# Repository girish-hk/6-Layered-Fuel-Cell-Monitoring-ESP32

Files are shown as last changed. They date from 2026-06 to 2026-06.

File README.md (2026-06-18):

# 6-Layered Fuel Cell Monitoring ESP32

A six-layer fuel cell monitoring PCB designed in KiCad for accurate voltage and current measurement. The system integrates analog signal conditioning, precision ADC interfaces, and an ESP32-S3 microcontroller for data acquisition and processing.

## Features

* 6-layer PCB design
* Fuel cell voltage monitoring
* Fuel cell current monitoring
* ESP32-S3 integration
* Custom KiCad symbols and footprints
* 3D PCB model

## Tools

* KiCad
* ESP32-S3
* Git & GitHub

## Preview

PCB Layout and 3D Render included in the repository.

## Author

Girish H K

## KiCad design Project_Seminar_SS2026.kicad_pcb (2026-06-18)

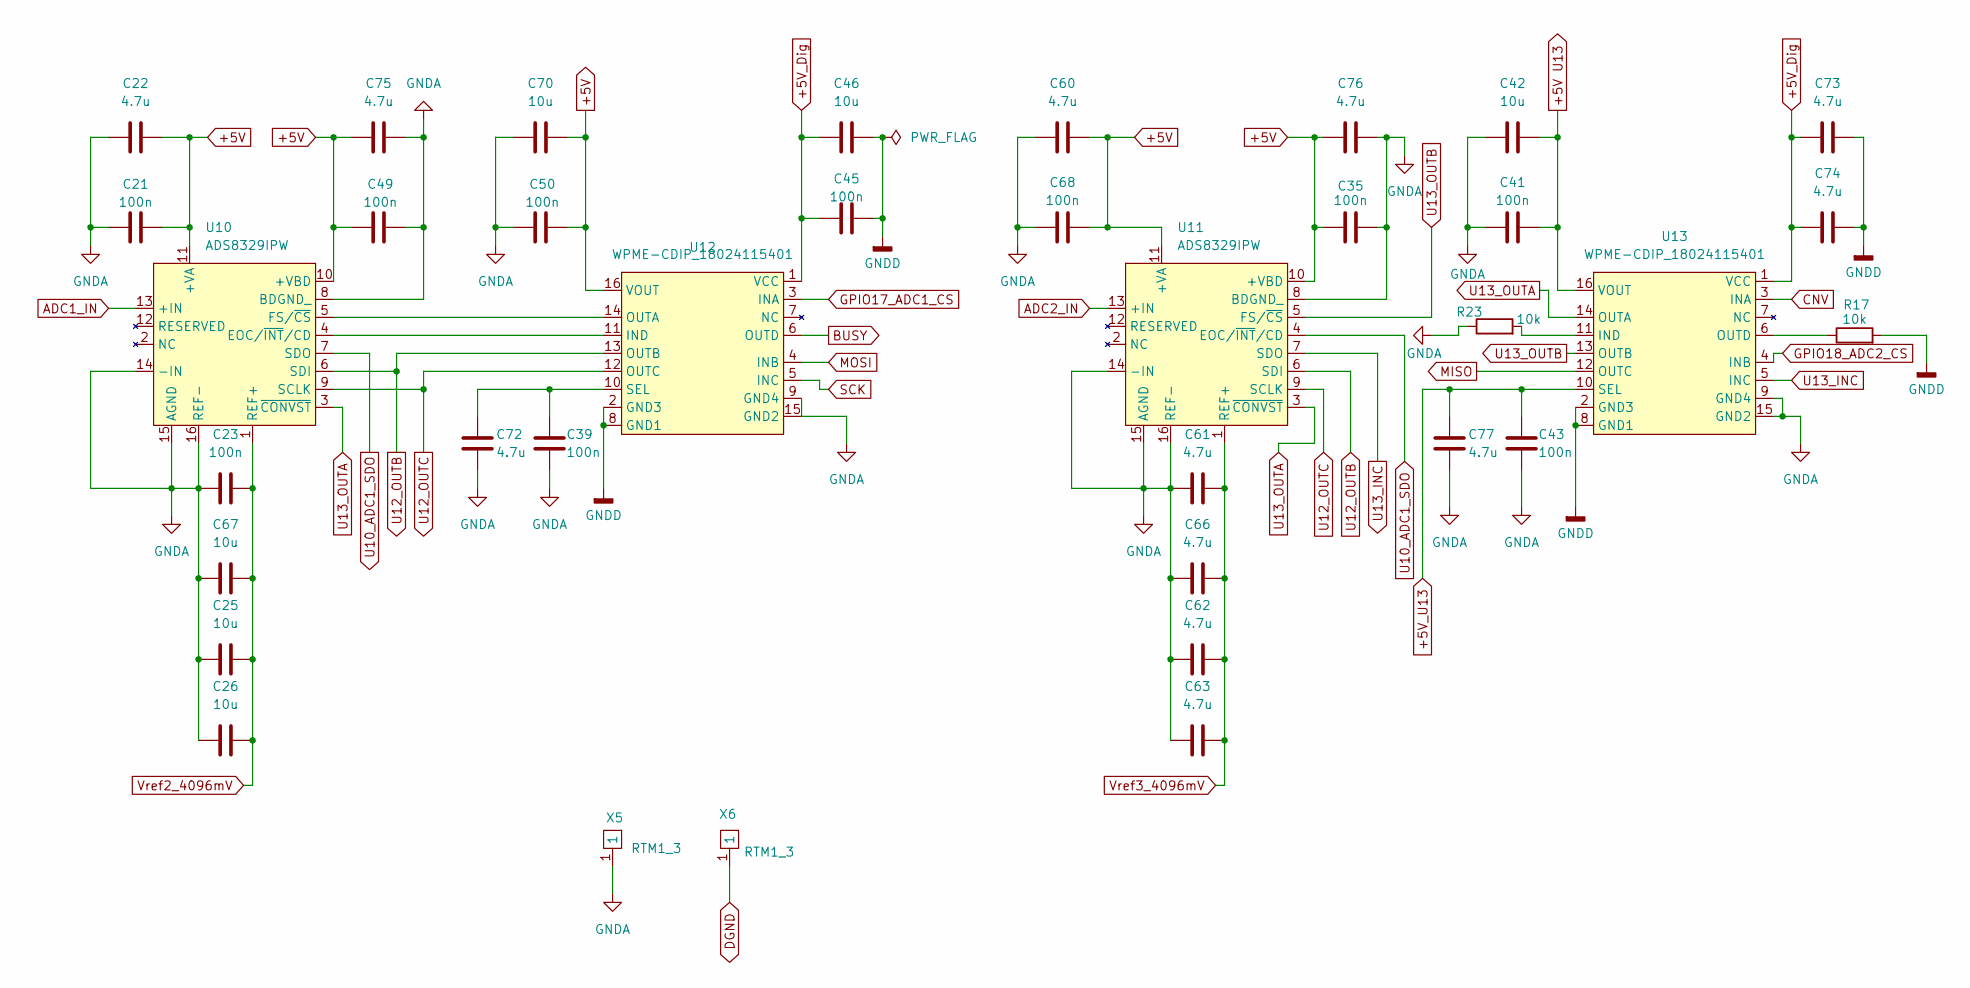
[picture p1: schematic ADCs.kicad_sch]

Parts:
C21, C23, C35, C39, C41, C43, C45, C49, C50, C68: 100n; C_0402_1005Metric
C22, C60, C61, C62, C63, C66, C72, C73, C74, C75, C76, C77: 4.7u; C_0402_1005Metric
C25, C26, C42, C46, C67, C70: 10u; C_0402_1005Metric
R17, R23: 10k; R_0402_1005Metric
U10, U11: ADS8329IPW; ADS8329
U12, U13: WPME-CDIP_18024115401
X5, X6: RTM1_3; rtm

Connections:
+5V: C21.2, C22.2, C35.1, C49.1, C50.2, C60.2, C68.2, C70.2, C75.1, C76.1, U10.10 (+VBD), U10.11 (+VA), U11.10 (+VBD), U11.11 (+VA), U12.16 (VOUT); also elsewhere on the board
+5V U13: C41.2, C42.2, U13.16 (VOUT)
+5V_Dig: C45.1, C46.1, C73.1, C74.1, U12.1 (VCC), U13.1 (VCC); also elsewhere on the board
+5V_U13: C43.2, C77.2, U13.10 (SEL)
ADC1_IN: U10.13 (+IN); also elsewhere on the board
ADC2_IN: U11.13 (+IN); also elsewhere on the board
BUSY: U12.6 (OUTD); also elsewhere on the board
CNV: U13.3 (INA); also elsewhere on the board
DGND: X6.1; also elsewhere on the board
GNDA: C21.1, C22.1, C23.1, C25.1, C26.1, C35.2, C39.1, C41.1, C42.1, C43.1, C49.2, C50.1, C60.1, C61.1, C62.1, C63.1, C66.1, C67.1, C68.1, C70.1, C72.1, C75.2, C76.2, C77.1, R23.1, U10.8 (BDGND_), U10.14 (-IN), U10.15 (AGND), U10.16 (REF−), U11.8 (BDGND_), U11.14 (-IN), U11.15 (AGND), U11.16 (REF−), U12.9 (GND4), U12.15 (GND2), U13.9 (GND4), U13.15 (GND2), X5.1; also elsewhere on the board
GNDD: C45.2, C46.2, C73.2, C74.2, R17.2, U12.2 (GND3), U12.8 (GND1), U13.2 (GND3), U13.8 (GND1)
GPIO17_ADC1_CS: U12.3 (INA); also elsewhere on the board
GPIO18_ADC2_CS: U13.4 (INB); also elsewhere on the board
MISO: U13.12 (OUTC); also elsewhere on the board
MOSI: U12.4 (INB); also elsewhere on the board
unnamed: U10.4 (EOC/~INT/CD), U12.11 (IND)
unnamed: U10.5 (FS/~CS), U12.14 (OUTA)
unnamed: C39.2, C72.2, U12.10 (SEL)
unnamed: R23.2, U13.11 (IND)
unnamed: R17.1, U13.6 (OUTD)
SCK: U12.5 (INC); also elsewhere on the board
U10_ADC1_SDO: U10.7 (SDO), U11.4 (EOC/~INT/CD)
U12_OUTB: U10.6 (SDI), U11.6 (SDI), U12.13 (OUTB)
U12_OUTC: U10.9 (SCLK), U11.9 (SCLK), U12.12 (OUTC)
U13_INC: U11.7 (SDO), U13.5 (INC)
U13_OUTA: U10.3 (~CONVST), U11.3 (~CONVST), U13.14 (OUTA)
U13_OUTB: U11.5 (FS/~CS), U13.13 (OUTB)
Vref2_4096mV: C23.2, C25.2, C26.2, C67.2, U10.1 (REF+); also elsewhere on the board
Vref3_4096mV: C61.2, C62.2, C63.2, C66.2, U11.1 (REF+)

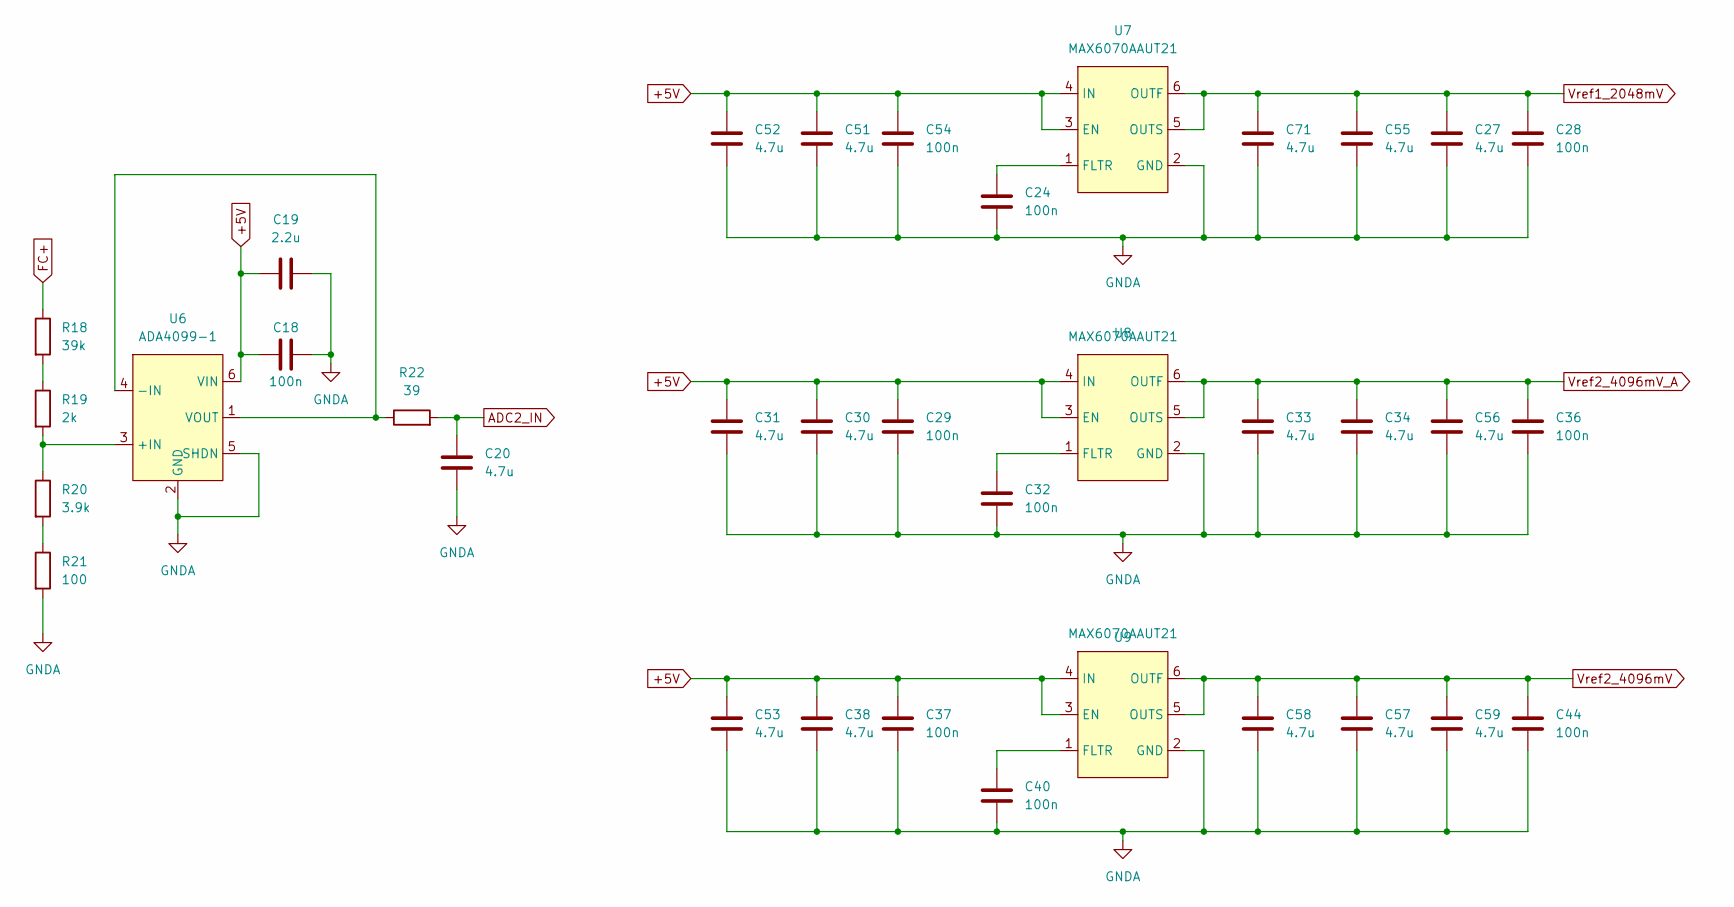
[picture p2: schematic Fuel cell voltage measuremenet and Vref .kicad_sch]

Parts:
C18, C24, C28, C29, C32, C36, C37, C40, C44, C54: 100n; C_0402_1005Metric
C19: 2.2u; C_0402_1005Metric
C20, C27, C30, C31, C33, C34, C38, C51, C52, C53, C55, C56, C57, C58, C59, C71: 4.7u; C_0402_1005Metric
R18: 39k; R_0603_1608Metric
R19: 2k; R_0603_1608Metric
R20: 3.9k; R_0603_1608Metric
R21: 100; R_0603_1608Metric
R22: 39; R_0402_1005Metric
U6: ADA4099-1; ADA4099
U7, U8, U9: MAX6070AAUT21; MAX6070

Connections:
+5V: C18.1, C19.1, C29.1, C30.1, C31.1, C37.1, C38.1, C51.1, C52.1, C53.1, C54.1, U6.6 (VIN), U7.3 (EN), U7.4 (IN), U8.3 (EN), U8.4 (IN), U9.3 (EN), U9.4 (IN); also elsewhere on the board
ADC2_IN: C20.1, R22.2; also elsewhere on the board
FC+: R18.1; also elsewhere on the board
GNDA: C18.2, C19.2, C20.2, C24.2, C27.2, C28.2, C29.2, C30.2, C31.2, C32.2, C33.2, C34.2, C36.2, C37.2, C38.2, C40.2, C44.2, C51.2, C52.2, C53.2, C54.2, C55.2, C56.2, C57.2, C58.2, C59.2, C71.2, R21.2, U6.2 (GND), U6.5 (SHDN), U7.2 (GND), U8.2 (GND), U9.2 (GND); also elsewhere on the board
unnamed: R18.2, R19.1
unnamed: R20.2, R21.1
unnamed: R19.2, R20.1, U6.3 (+IN)
unnamed: R22.1, U6.1 (VOUT), U6.4 (-IN)
unnamed: C24.1, U7.1 (FLTR)
unnamed: C32.1, U8.1 (FLTR)
unnamed: C40.1, U9.1 (FLTR)
Vref1_2048mV: C27.1, C28.1, C55.1, C71.1, U7.5 (OUTS), U7.6 (OUTF); also elsewhere on the board
Vref2_4096mV: C44.1, C57.1, C58.1, C59.1, U9.5 (OUTS), U9.6 (OUTF); also elsewhere on the board
Vref2_4096mV_A: C33.1, C34.1, C36.1, C56.1, U8.5 (OUTS), U8.6 (OUTF)

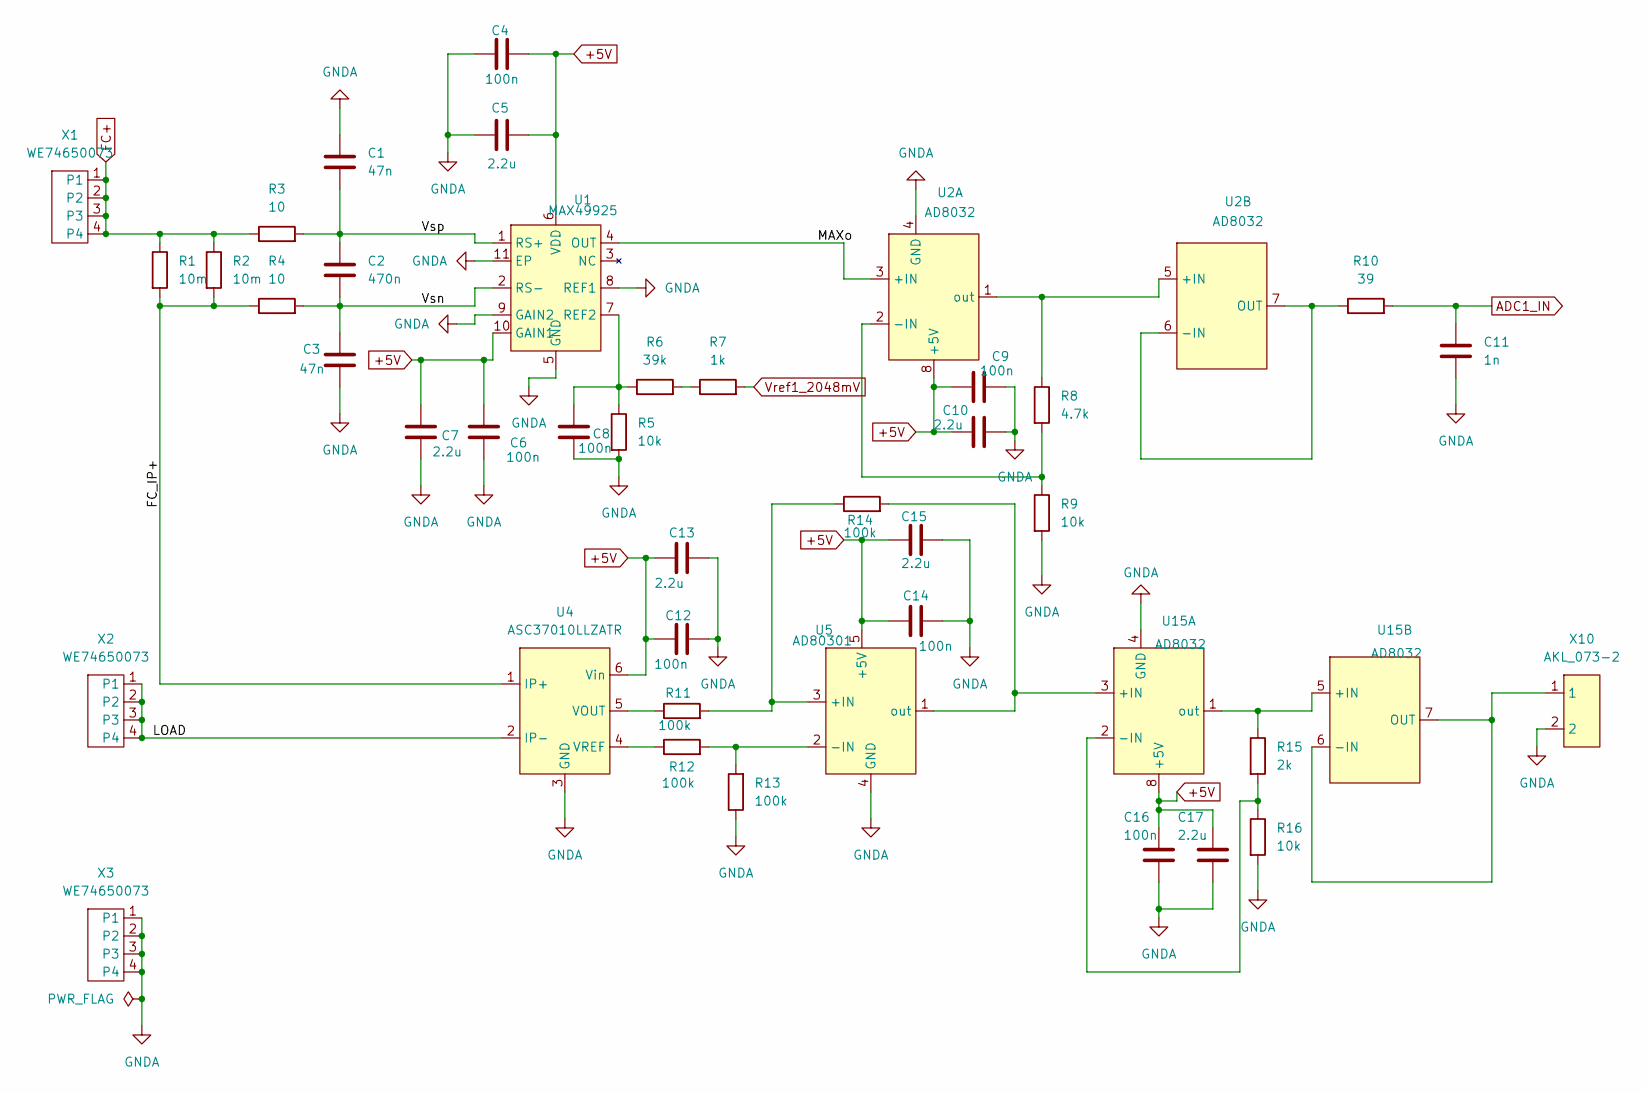
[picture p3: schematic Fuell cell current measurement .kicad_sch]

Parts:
C1, C3: 47n; C_0603_1608Metric
C2: 470n; C_0603_1608Metric
C4, C6, C8, C9, C12, C14, C16: 100n; C_0402_1005Metric
C5, C7, C10, C13, C15, C17: 2.2u; C_0402_1005Metric
C11: 1n; C_0402_1005Metric
R1, R2: 10m; R_2512_6332Metric
R3, R4: 10; R_0603_1608Metric
R5, R9, R16: 10k; R_0402_1005Metric
R6: 39k; R_0402_1005Metric
R7: 1k; R_0402_1005Metric
R8: 4.7k; R_0402_1005Metric
R10: 39; R_0402_1005Metric
R11, R12, R13, R14: 100k; R_0402_1005Metric
R15: 2k; R_0402_1005Metric
U1: MAX49925; MAX49925_TDFN10_3x3_EP
U2, U15: AD8032
U4: ASC37010LLZATR; ACS37010LLZATR-030U5
U5: AD80301; AD8031
X1, X2, X3: WE74650073; WP-THRBU REDCUBE 74650073
X10: AKL_073-2; AKLO73-2

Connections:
+5V: C4.2, C5.2, C6.1, C7.1, C9.1, C10.1, C12.1, C13.1, C14.1, C15.1, C16.2, C17.1, U1.6 (VDD), U1.10 (GAIN1), U2.8 (+5V), U4.6 (Vin), U5.5 (+5V), U15.8 (+5V); also elsewhere on the board
/Fuel cell current measurement (page 2)/FC_IP+: R1.2, R2.2, R4.1, U4.1 (IP+)
/Fuel cell current measurement (page 2)/LOAD: U4.2 (IP-), X2.1, X2.2, X2.3, X2.4
/Fuel cell current measurement (page 2)/MAXo: U1.4 (OUT), U2.3 (+IN)
/Fuel cell current measurement (page 2)/Vsn: C2.2, C3.1, R4.2, U1.2 (RS-)
/Fuel cell current measurement (page 2)/Vsp: C1.2, C2.1, R3.2, U1.1 (RS+)
ADC1_IN: C11.1, R10.2; also elsewhere on the board
FC+: R1.1, R2.1, R3.1, X1.1, X1.2, X1.3, X1.4; also elsewhere on the board
GNDA: C1.1, C3.2, C4.1, C5.1, C6.2, C7.2, C8.2, C9.2, C10.2, C11.2, C12.2, C13.2, C14.2, C15.2, C16.1, C17.2, R5.2, R9.2, R13.1, R16.2, U1.5 (GND), U1.8 (REF1), U1.9 (GAIN2), U1.11 (EP), U2.4 (GND), U4.3 (GND), U5.4 (GND), U15.4 (GND), X3.1, X3.2, X3.3, X3.4, X10.2; also elsewhere on the board
unnamed: R6.2, R7.1
unnamed: C8.1, R5.1, R6.1, U1.7 (REF2)
unnamed: R8.2, R9.1, U2.2 (-IN)
unnamed: R8.1, U2.1 (out), U2.5 (+IN)
unnamed: R10.1, U2.6 (-IN), U2.7 (OUT)
unnamed: R11.1, U4.5 (VOUT)
unnamed: R12.1, U4.4 (VREF)
unnamed: R11.2, R14.1, U5.3 (+IN)
unnamed: R12.2, R13.2, U5.2 (-IN)
unnamed: R14.2, U5.1 (out), U15.3 (+IN)
unnamed: R15.2, R16.1, U15.2 (-IN)
unnamed: R15.1, U15.1 (out), U15.5 (+IN)
unnamed: U15.6 (-IN), U15.7 (OUT), X10.1
Vref1_2048mV: R7.2; also elsewhere on the board

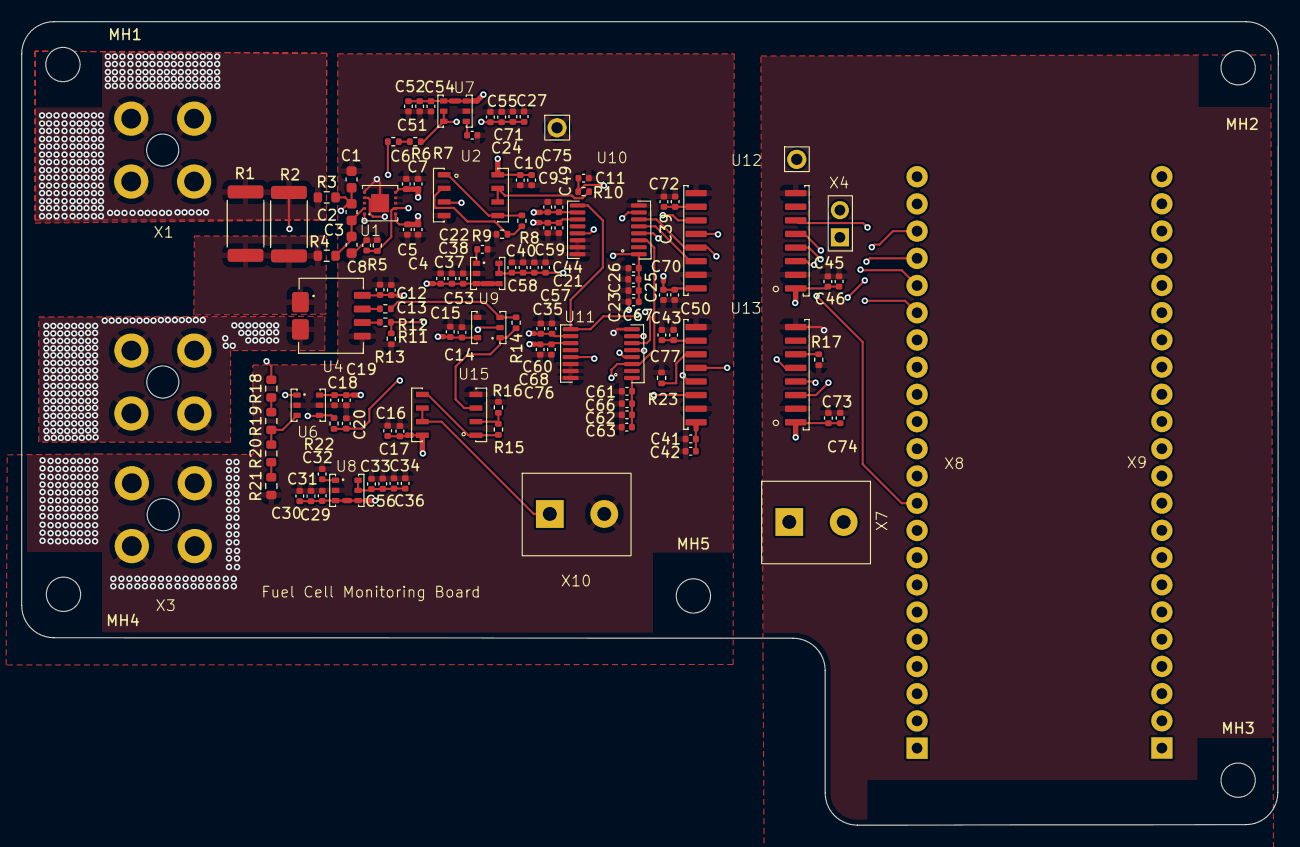
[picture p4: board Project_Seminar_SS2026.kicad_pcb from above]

Board: 6 copper layers, 117.3 x 75.0 mm, 123 parts (0 on the bottom side), 58 nets.

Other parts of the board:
MH1, MH2, MH3, MH4, MH5: MountingHole_3.2mm_M3
X4: MPE-087; MPE-087-1-002
X7: AKL_073-2; AKLO73-2
X8: BCS-122-L-S-TE_L; BCS-122-L-S-TE
X9: BCS-122-L-S-TE

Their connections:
+5V_Dig: X4.1, X7.1; also elsewhere on the board
BUSY: X8.15; also elsewhere on the board
CNV: X8.20; also elsewhere on the board
DGND: X7.2, X8.22, X9.21, X9.22; also elsewhere on the board
GPIO17_ADC1_CS: X8.10; also elsewhere on the board
GPIO18_ADC2_CS: X8.11; also elsewhere on the board
MISO: X8.19; also elsewhere on the board
MOSI: X8.17; also elsewhere on the board
unnamed: X4.2, X8.21
SCK: X8.18; also elsewhere on the board

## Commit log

2026-06-03 Initial commit of 6-layer fuel cell measurement PCB
    [21-0137_T10331C_ADI.step, 398800402.stp, 74650073 (rev1).stp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]
2026-06-03 updated 3D models
    [21-0137_T10331C_ADI.step, 398800402.stp, 74650073 (rev1).stp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]
2026-06-18 Updated PCB design of Solder mask
    [Project_Seminar_SS2026.kicad_pcb]
